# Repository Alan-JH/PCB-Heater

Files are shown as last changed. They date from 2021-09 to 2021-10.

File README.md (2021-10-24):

# PCB-Heater

Solder reflow hotplate design based on Carl Bugeja's idea and proof of concept.

Aluminum PCB as the resistive heating element, 200x200mm. Control board is separated and has displays for time and temperature (target and actual), and an SD card to read reflow profiles and save data to. Runs off of 3.3V logic and the ATTiny1614/1624 MCU. Input voltage (for the heating element) can range up to around 50V by design (Plan to use 36-48V), and the element itself should have a resistance of 5.1Ohm at 25C. Target maximum temperature is around 200C. Optional cooling provided by a 5V fan.

v1.0 results: 215C max temperature, 25 to 200C in around 4 minutes. 5 ohm resistance at room temperature, 10 ohm at 200C

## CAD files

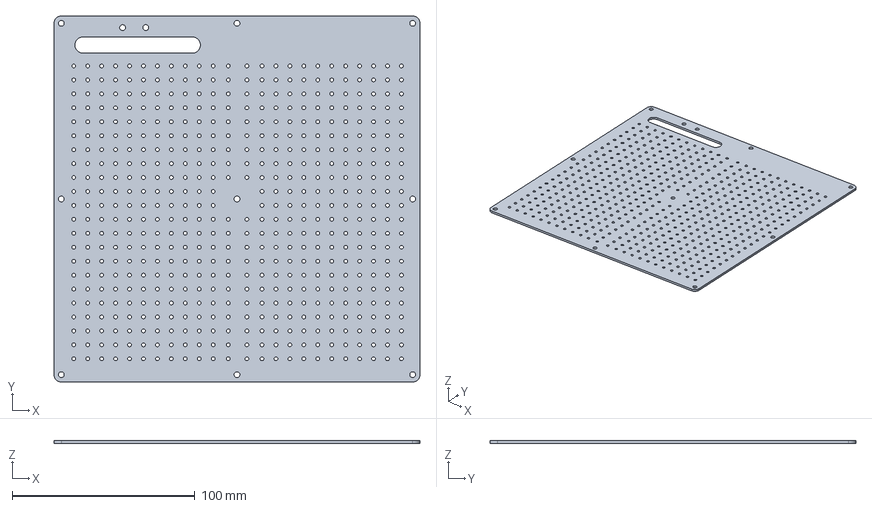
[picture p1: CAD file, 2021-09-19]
ECAD/Heater.step
200.0 x 200.0 x 1.60 mm

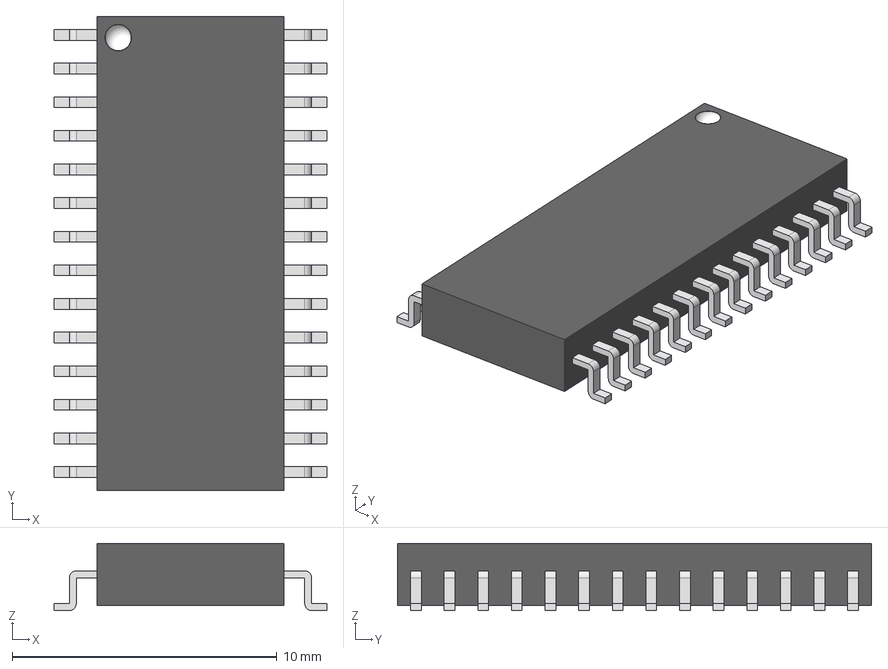
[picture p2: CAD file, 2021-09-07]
ECAD/3D models/Holtek_-_HT16K33-SOP28.step
10.3 x 17.9 x 2.54 mm

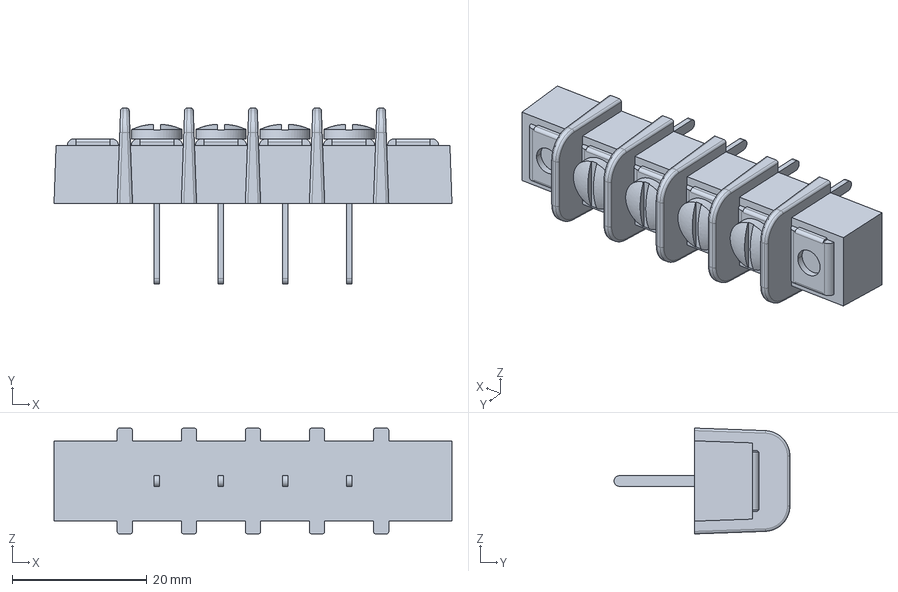
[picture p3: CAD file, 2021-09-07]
ECAD/3D models/387112204.stp
59.2 x 26.2 x 15.7 mm

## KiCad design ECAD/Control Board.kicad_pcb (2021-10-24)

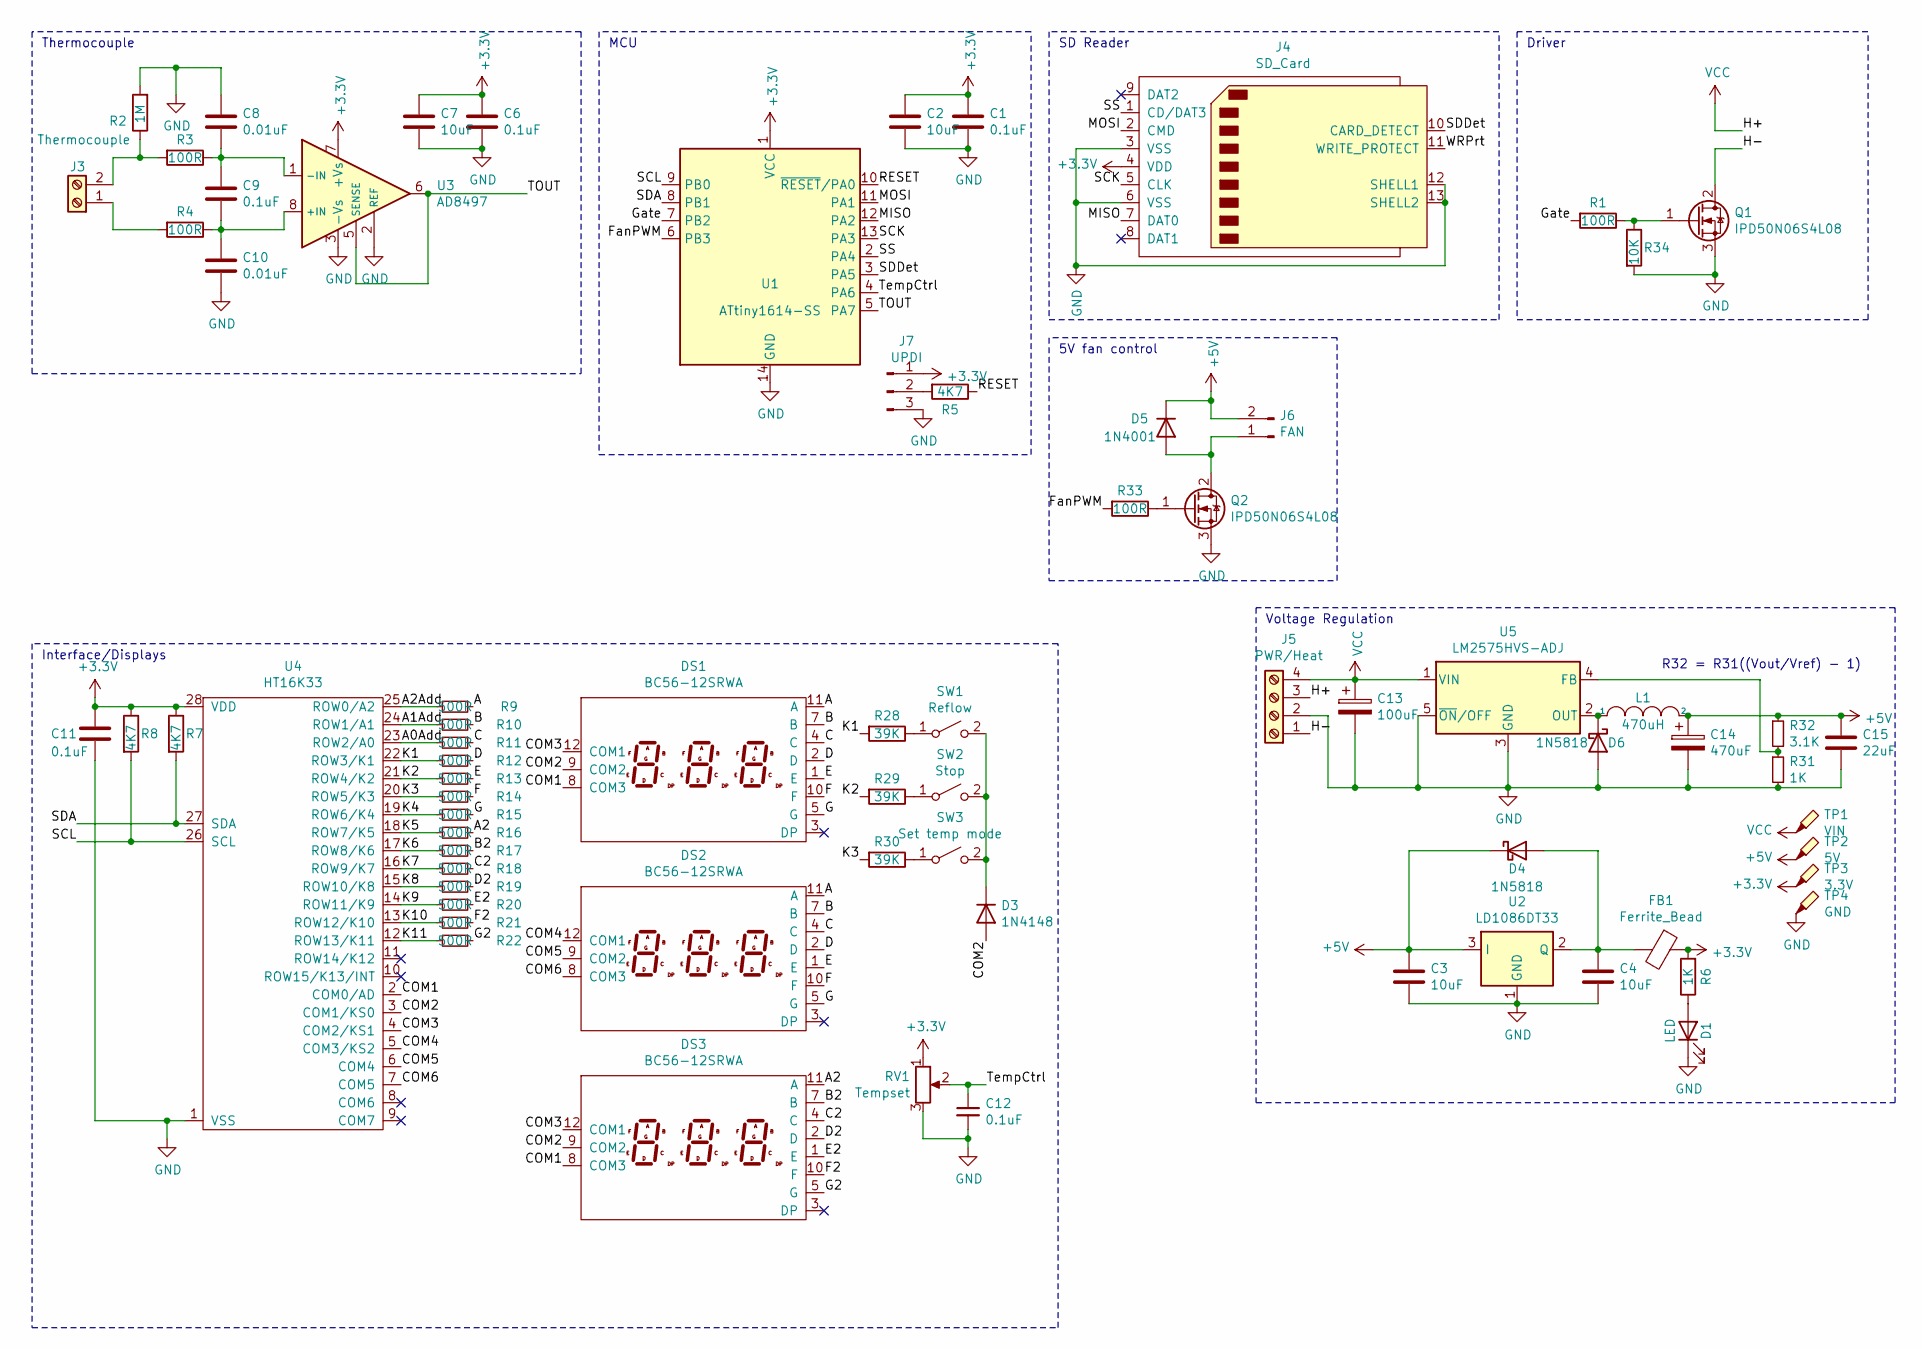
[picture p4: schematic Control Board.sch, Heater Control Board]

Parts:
C1, C6, C9, C11, C12: 0.1uF; C_0805_2012Metric_Pad1.18x1.45mm_HandSolder
C2, C3, C4, C7: 10uF; C_0805_2012Metric_Pad1.18x1.45mm_HandSolder
C8, C10: 0.01uF; C_0805_2012Metric_Pad1.18x1.45mm_HandSolder
C13: 100uF; CP_Elec_10x10.5
C14: 470uF; CP_Elec_8x10.5
C15: 22uF; C_0805_2012Metric_Pad1.18x1.45mm_HandSolder
D1: LED; LED_0805_2012Metric_Pad1.15x1.40mm_HandSolder
D3: 1N4148; D_0805_2012Metric_Pad1.15x1.40mm_HandSolder
D4, D6: 1N5818; D_T-1_P5.08mm_Horizontal
D5: 1N4001; D_T-1_P5.08mm_Horizontal
DS1, DS2, DS3: BC56-12SRWA
FB1: Ferrite_Bead; R_0805_2012Metric_Pad1.20x1.40mm_HandSolder
J3: Thermocouple; CUI-TB006-508-02BE
J4: SD_Card; SD_TE_2041021
J5: PWR/Heat; Molex-38711-2204
J6: FAN; PinHeader_1x02_P2.54mm_Vertical
J7: UPDI; PinHeader_1x03_P2.54mm_Vertical
L1: 470uH; L_12x12mm_H8mm
Q1, Q2: IPD50N06S4L08; TO-252-2
R1, R3, R4, R33: 100R; R_1206_3216Metric_Pad1.30x1.75mm_HandSolder
R2: 1M; R_1206_3216Metric_Pad1.30x1.75mm_HandSolder
R5, R7, R8: 4K7; R_1206_3216Metric_Pad1.30x1.75mm_HandSolder
R6: 1K; R_1206_3216Metric_Pad1.30x1.75mm_HandSolder
R9, R10, R11, R12, R13, R14, R15, R16, R17, R18, R19, R20, R21, R22: 500R; R_0805_2012Metric_Pad1.20x1.40mm_HandSolder
R28, R29, R30: 39K; R_1206_3216Metric_Pad1.30x1.75mm_HandSolder
R31: 1K; R_0805_2012Metric_Pad1.20x1.40mm_HandSolder
R32: 3.1K; R_0805_2012Metric_Pad1.20x1.40mm_HandSolder
R34: 10K; R_1206_3216Metric_Pad1.30x1.75mm_HandSolder
RV1: Tempset; PinHeader_1x03_P2.54mm_Vertical
SW1: Reflow; SW_PUSH_6mm_H7.3mm
SW2: Stop; SW_PUSH_6mm_H7.3mm
SW3: Set temp mode; SW_PUSH_6mm_H7.3mm
TP1: VIN; TestPoint_Pad_2.0x2.0mm
TP2: 5V; TestPoint_Pad_2.0x2.0mm
TP3: 3.3V; TestPoint_Pad_2.0x2.0mm
TP4: GND; TestPoint_Pad_2.0x2.0mm
U1: ATtiny1614-SS; SOIC-14_3.9x8.7mm_P1.27mm
U2: LD1086DT33; TO-252-3_TabPin2
U3: AD8497; MSOP-8_3x3mm_P0.65mm
U4: HT16K33; Holtek-HT16K33-SOP28-0
U5: LM2575HVS-ADJ; TO-263-5_TabPin3

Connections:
+3V3: C1.1, C2.1, C6.1, C7.1, C11.1, FB1.1, J4.4 (VDD), J7.1, R6.2, R7.1, R8.1, RV1.1, TP3.1, U1.1 (VCC), U3.7 (+Vs), U4.28 (VDD)
+5V: C3.1, C14.1, C15.1, D4.1 (K), D5.1 (K), J6.2, L1.2, R32.1, TP2.1, U2.3 (I)
/A: DS1.11 (A), DS2.11 (A), R9.1
/A0Add: R11.2, U4.23 (ROW2/A0)
/A1Add: R10.2, U4.24 (ROW1/A1)
/A2: DS3.11 (A), R16.1
/A2Add: R9.2, U4.25 (ROW0/A2)
/B: DS1.7 (B), DS2.7 (B), R10.1
/B2: DS3.7 (B), R17.1
/C: DS1.4 (C), DS2.4 (C), R11.1
/C2: DS3.4 (C), R18.1
/COM1: DS1.8 (COM3), DS3.8 (COM3), U4.2 (COM0/AD)
/COM2: D3.2 (A), DS1.9 (COM2), DS3.9 (COM2), U4.3 (COM1/KS0)
/COM3: DS1.12 (COM1), DS3.12 (COM1), U4.4 (COM2/KS1)
/COM4: DS2.12 (COM1), U4.5 (COM3/KS2)
/COM5: DS2.9 (COM2), U4.6 (COM4)
/COM6: DS2.8 (COM3), U4.7 (COM5)
/D: DS1.2 (D), DS2.2 (D), R12.1
/D2: DS3.2 (D), R19.1
/E: DS1.1 (E), DS2.1 (E), R13.1
/E2: DS3.1 (E), R20.1
/F: DS1.10 (F), DS2.10 (F), R14.1
/F2: DS3.10 (F), R21.1
/FanPWM: R33.2, U1.6 (PB3)
/G: DS1.5 (G), DS2.5 (G), R15.1
/G2: DS3.5 (G), R22.1
/Gate: R1.2, U1.7 (PB2)
/H-: J5.1, Q1.2 (D)
/K1: R12.2, R28.2, U4.22 (ROW3/K1)
/K2: R13.2, R29.2, U4.21 (ROW4/K2)
/K3: R14.2, R30.2, U4.20 (ROW5/K3)
/K4: R15.2, U4.19 (ROW6/K4)
/K5: R16.2, U4.18 (ROW7/K5)
/K6: R17.2, U4.17 (ROW8/K6)
/K7: R18.2, U4.16 (ROW9/K7)
/K8: R19.2, U4.15 (ROW10/K8)
/K9: R20.2, U4.14 (ROW11/K9)
/K10: R21.2, U4.13 (ROW12/K10)
/K11: R22.2, U4.12 (ROW13/K11)
/MISO: J4.7 (DAT0), U1.12 (PA2)
/MOSI: J4.2 (CMD), U1.11 (PA1)
/RESET: R5.1, U1.10 (~RESET~/PA0)
/SCK: J4.5 (CLK), U1.13 (PA3)
/SCL: R8.2, U1.9 (PB0), U4.26 (SCL)
/SDA: R7.2, U1.8 (PB1), U4.27 (SDA)
/SDDet: J4.10 (CARD_DETECT), U1.3 (PA5)
/SS: J4.1 (CD/DAT3), U1.2 (PA4)
/TOUT: U1.5 (PA7), U3.5 (SENSE), U3.6
/TempCtrl: C12.1, RV1.2, U1.4 (PA6)
GND: C1.2, C2.2, C3.2, C4.2, C6.2, C7.2, C8.1, C10.2, C11.2, C12.2, C13.2, C14.2, C15.2, D1.1 (K), D6.2 (A), J4.3 (VSS), J4.6 (VSS), J4.12 (SHELL1), J4.13 (SHELL2), J5.2, J7.3, Q1.3 (S), Q2.3 (S), R2.2, R31.2, R34.2, RV1.3, TP4.1, U1.14 (GND), U2.1 (GND), U3.2 (REF), U3.3 (-Vs), U4.1 (VSS), U5.3 (GND), U5.5 (~ON~/OFF)
unnamed: C4.1, D4.2 (A), FB1.2, U2.2 (Q)
unnamed: C8.2, C9.1, R3.1, U3.1 (-IN)
unnamed: C9.2, C10.1, R4.1, U3.8 (+IN)
unnamed: D1.2 (A), R6.1
unnamed: D3.1 (K), SW1.2 (B), SW2.2 (B), SW3.2 (B)
unnamed: D5.2 (A), J6.1, Q2.2 (D)
unnamed: D6.1 (K), L1.1, U5.2 (OUT)
unnamed: J3.1, R4.2
unnamed: J3.2, R2.1, R3.2
unnamed: J7.2, R5.2
unnamed: Q1.1 (G), R1.1, R34.1
unnamed: Q2.1 (G), R33.1
unnamed: R28.1, SW1.1 (A)
unnamed: R29.1, SW2.1 (A)
unnamed: R30.1, SW3.1 (A)
unnamed: R31.1, R32.2, U5.4 (FB)
VCC: C13.1, J5.3, J5.4, TP1.1, U5.1 (VIN)

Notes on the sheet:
Thermocouple
Driver
SD Reader
Interface/Displays
MCU
5V fan control
R32 = R31((Vout/Vref) - 1)
Voltage Regulation

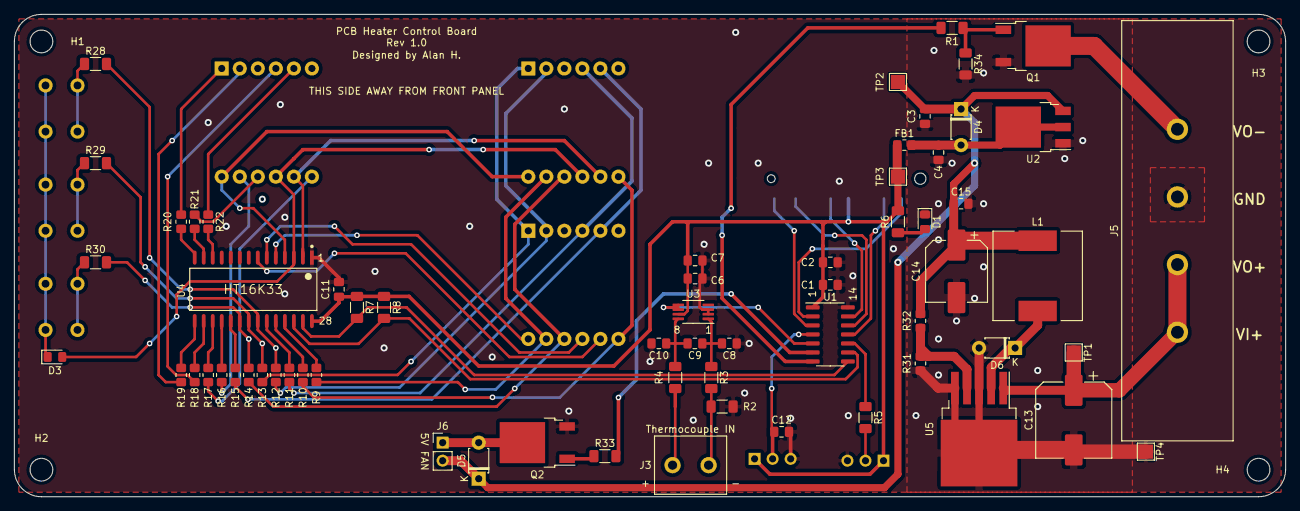
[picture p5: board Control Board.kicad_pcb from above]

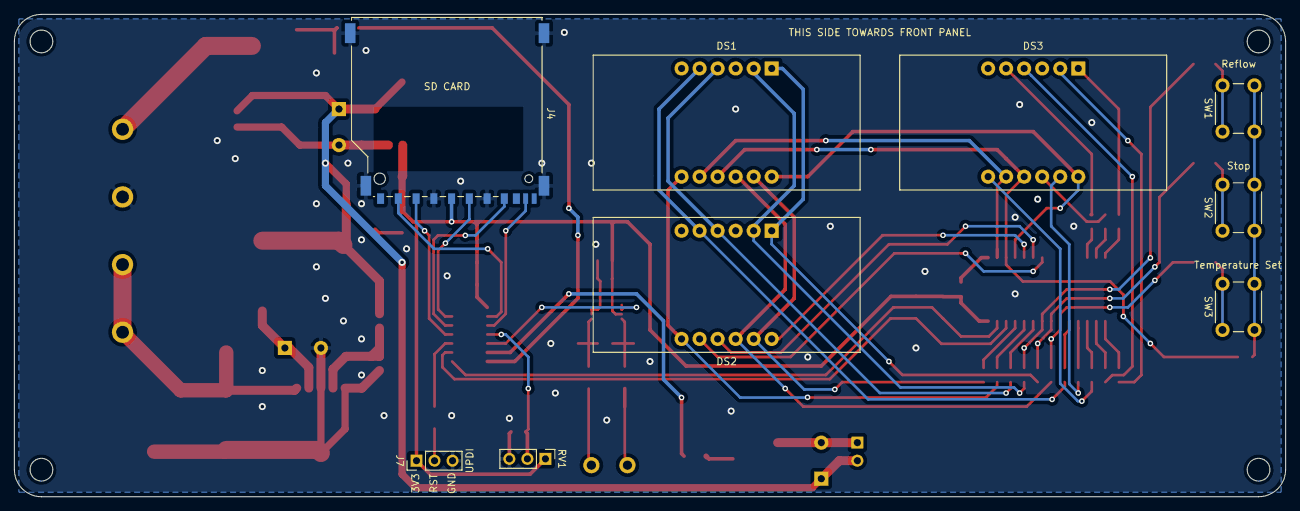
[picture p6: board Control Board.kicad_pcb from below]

Board: 2 copper layers, 179.1 x 67.9 mm, 77 parts (9 on the bottom side), 67 nets.

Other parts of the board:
H1, H2, H3, H4: MountingHole_3.2mm_M3

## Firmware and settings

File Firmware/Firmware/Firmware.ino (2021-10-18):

#include <PID_v1.h>
#include <ht16k33.h>
#include <Wire.h>
#include "SegmentMap.h"
#include "ReflowProfile.h"

HT16K33 HT;
#define HEATPIN 5 //PWM out pin for heatplate driver MOSFET
#define THERMOCPL 3 //Analog in pin for thermocouple/AD8497 input

#define DISPINTERVAL 20 //How many loop iterations before display is updated
int dispct = 0; //Counter value to update display

double setPoint, Input, Output; //PID values
int reflowStage = 0; //Current reflow stage
unsigned long lastStageTime = 0; //last stage change time in ms
unsigned long lastRecordTime = 0; //generic last time variable, in ms
bool pastPeak = false; //whether the temperature has passed peak temp

double kp = 2.5, ki = 0.5, kd = 5; //PID parameters to tune

PID HeatPID(&Input, &Output, &setPoint, kp, ki, kd, DIRECT);

void setup() {
  //HT16K33 begin
  HT.begin(0x00);
  HT.clearAll();

  //Initialize pins, set heater to low immediately
  pinMode(HEATPIN, OUTPUT);
  digitalWrite(HEATPIN, LOW);
  pinMode(THERMOCPL, INPUT);

  //Start PID
  HeatPID.SetMode(AUTOMATIC);
  setPoint = 24;

  //Start profile (remove once start button is added)
  startProfile();
}

void setDisp1(int temp){ //Updates display 1: actual temperature
  int dig1 = temp%10;
  int dig2 = (temp/10)%10;
  int dig3 = (temp/100)%10;

  uint8_t dig1bin = 0;
  uint8_t dig2bin = 0;
  uint8_t dig3bin = 0;
  for (int i = 0; i < 7; i++){
    if (charMap[dig1][i] == 1)
      dig1bin |= segDigMap[2][i][1];
    if (charMap[dig2][i] == 1)
      dig2bin |= segDigMap[1][i][1];
    if (charMap[dig3][i] == 1)
      dig3bin |= segDigMap[0][i][1];
  }
  HT.set7SegRaw(2, dig1bin);
  HT.set7SegRaw(1, dig2bin);
  HT.set7SegRaw(0, dig3bin);
}

void setDisp2(int target){ //Updates display 2: target temperature
  int dig1 = target%10;
  int dig2 = (target/10)%10;
  int dig3 = (target/100)%10;

  uint8_t dig1bin = 0;
  uint8_t dig2bin = 0;
  uint8_t dig3bin = 0;
  for (int i = 0; i < 7; i++){
    if (charMap[dig1][i] == 1)
      dig1bin |= segDigMap[8][i][1];
    if (charMap[dig2][i] == 1)
      dig2bin |= segDigMap[7][i][1];
    if (charMap[dig3][i] == 1)
      dig3bin |= segDigMap[6][i][1];
  }
  HT.set7SegRaw(3, dig1bin);
  HT.set7SegRaw(4, dig2bin);
  HT.set7SegRaw(5, dig3bin);
}

void startProfile(){ //Starts reflow profile
  lastStageTime = millis();
  kp = 2.5;
  ki = 0.5;
  kd = 5;
  reflowStage = 0;
  setPoint = stageTemps[0];
}

void updateProfile(){ //Updates reflow profile, changes stages, updates setpoint if needed
  switch (reflowStage){
    case 0: //First stage ramp rate doesn't really matter, so just set the setpoint in startProfile() and move to next stage when the time comes
      if ((millis()-lastStageTime)/1000 > stageTimes[0]){
        reflowStage ++;
        lastStageTime = millis();
        lastRecordTime = millis();
      }
      break;
    case 1: //Second stage needs to maintain a relatively slow ramp, so step the setpoint up at constant rate over time until next stage
      if (millis() - lastRecordTime > 500){
        setPoint += ((0.5)*(stageTemps[1]-stageTemps[0])/(stageTimes[1]));
        lastRecordTime = millis();
      }
      if ((millis()-lastStageTime)/1000 > stageTimes[1]){
        reflowStage ++;
        lastStageTime = millis();
      }
      break;
    case 2: //Third stage ramps to peak temperature as quickly as possible, and maintains peak for set amount of time
      setPoint = stageTemps[2];
      kp = 10;
      ki = 4;
      if (Input > PEAKTHRESHOLD && !pastPeak){
        lastRecordTime = millis();
        pastPeak = true;
      }
      if (pastPeak && (millis() - lastRecordTime)/1000 > stageTimes[2]){
        reflowStage ++;
        lastStageTime = millis();
      }
      break;
    case 3: //Cooldown, may incorporate fan usage later
      setPoint = 0;
      break;
  }
}

void loop() {
  float vtemp = analogRead(THERMOCPL)*3.3/1024; //raw voltage
  int temp = (int)((vtemp-0)/.005); //Convert to output with 0 VREF and 5mV/C step

  if (dispct == 0){ //Update displays if interval = 0
    HT.clearAll();
    setDisp1(temp);
    setDisp2((int)setPoint);
    dispct = DISPINTERVAL;
    HT.sendLed();
  }
  dispct --;

  Input = temp; //Set input
  HeatPID.Compute(); //Compute PID, write output
  analogWrite(HEATPIN, Output);

  updateProfile();
  delay(50);
}

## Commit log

2021-09-07 Cleanup
    Renamed files, removed temp files
    [Control Board.kicad_pcb, Control Board.sch, Heater.kicad_pcb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]
2021-09-07 Perforate Heatbed
    Added a grid of 2.1mm holes, which may help thermal performance.
    [Heater-B_Cu.gbr, Heater-B_Mask.gbr, Heater-B_Paste.gbr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]
2021-09-09 Widened traces to 30mil
    In order to reduce resistance and increase wattage, traces widened up to 30mil (theoretical 5.4R at 25C)
    [Heater.kicad_pcb]
2021-09-09 High voltage modifications
    Widened high voltage tracks and replaced schottky diode with higher back voltage diode.
    [Control Board.kicad_pcb, Control Board.sch]
2021-09-10 Revised control board schematic
    Replaced single LDO setup with cascaded LDOs, so that a higher input voltage can be used, and the intermediate 12V can be used to power a fan. Added the appropriate circuitry to control a fan. Added test points for each voltage level and ground.
    Layout is still to be updated
    [Control Board.sch]
2021-09-10 Added footprints to board
    [Control Board.kicad_pcb, Control Board.sch, Linear_Technology_-_LT3012EFE#TRPBF.step]
2021-09-10 Revert "Perforated heater"
    [Heater-B_Cu.gbr, Heater-B_Mask.gbr, Heater-B_Paste.gbr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]
2021-09-10 Revert "Merge pull request #3 from Alan-JH/revert-2-Perforated-Heater"
    This reverts commit 4dedab5329d0c4c589ebeff6f2ce44676f29a142, reversing
    changes made to 18337d37710a704d8d57a7691b9b75f48685949f.
    [Heater-B_Cu.gbr, Heater-B_Mask.gbr, Heater-B_Paste.gbr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]
2021-09-10 Update heater silkscreen info
    [Heater.kicad_pcb]
2021-09-11 Re-arrange components
    [Control Board.kicad_pcb, Control Board.sch]
2021-09-11 Added pulldown to mosfet gate
    [Control Board.kicad_pcb, Control Board.sch]
2021-09-13 Replaced primary LDO with LM317
    [Control Board.kicad_pcb, Control Board.sch]
2021-09-14 Replaced linear regulator with switching regulator
    Chose switching regulator for the sake of less heat. Undecided as to whether I will end up using a premade module or incorporating the circuitry
    Replaced 12V rail with 5V rail, to increase efficiency of the LDO. Requires a 5V fan now.
    Bumped revision number to 0.4
    [Control Board.sch]
2021-09-14 Remove extra LC filter, replace with ceramic cap
    [Control Board.sch]
2021-09-15 Associate footprints and update board
    [Control Board.kicad_pcb, Control Board.sch]
2021-09-16 Lay out switching regulator
    Also reshuffling the SD card and power port placements
    [Control Board.kicad_pcb, Control Board.sch]
2021-09-16 More routing
    [Control Board.kicad_pcb]
2021-09-19 Routed V0.4 Control Board
    Finished routing board, removed ununsed models and footprints, re-exported gerbers and .STEP files
    [Control Board-B_Cu.gbr, Control Board-B_Mask.gbr, Control Board-B_Paste.gbr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]
2021-09-20 BOM Export, minor via edits and gerber re-export
    [Control Board-B_Cu.gbr, Control Board-B_Mask.gbr, Control Board-B_Paste.gbr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]
2021-10-08 start fixing errors in board
    [Control Board.kicad_pcb, Control Board.sch]
2021-10-09 Finish rerouting LDO
    [Control Board-B_Cu.gbr, Control Board-B_Mask.gbr, Control Board-B_Paste.gbr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]
2021-10-10 Fix major silkscreen error, push to rev0.5
    [Control Board-B_Cu.gbr, Control Board-B_Mask.gbr, Control Board-B_Paste.gbr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]
2021-10-11 Fix thermocouple + and - pins
    [Control Board-B_Cu.gbr, Control Board-B_Mask.gbr, Control Board-B_Paste.gbr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]
2021-10-12 Firmware: implement PID
2021-10-12 Widen heater tracks
    reduce actual resistance from 7ohm to 5ohm
    [Heater.kicad_pcb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]
2021-10-12 attempt to fix pid
    [Firmware.ino]
2021-10-12 tune pid
2021-10-24 Push v1.0 release version
    [Control Board-B_Cu.gbr, Control Board-B_Mask.gbr, Control Board-B_Paste.gbr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]
